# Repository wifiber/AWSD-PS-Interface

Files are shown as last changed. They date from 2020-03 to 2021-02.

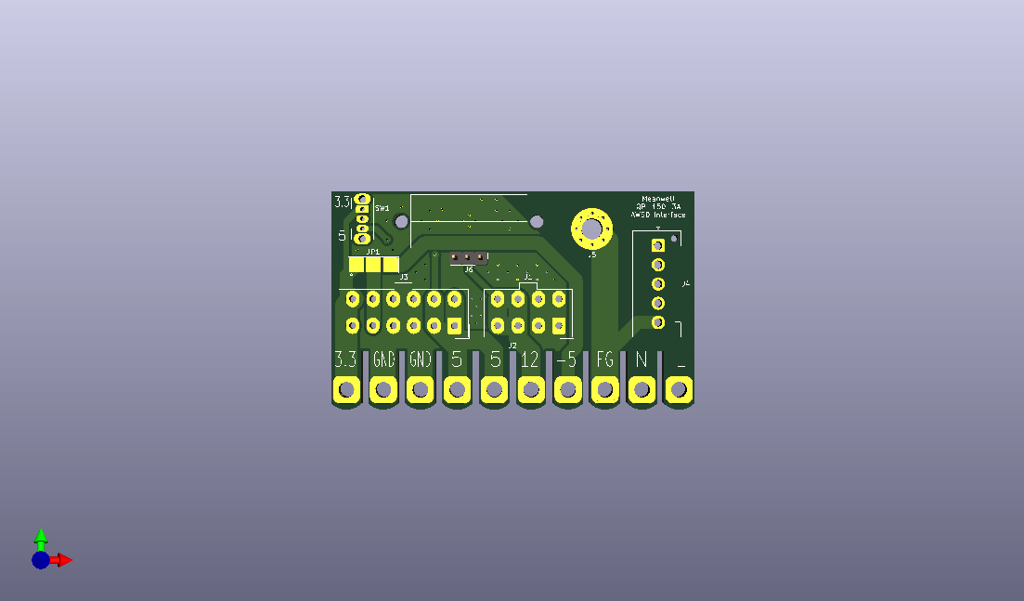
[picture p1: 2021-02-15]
psinterface-top.png

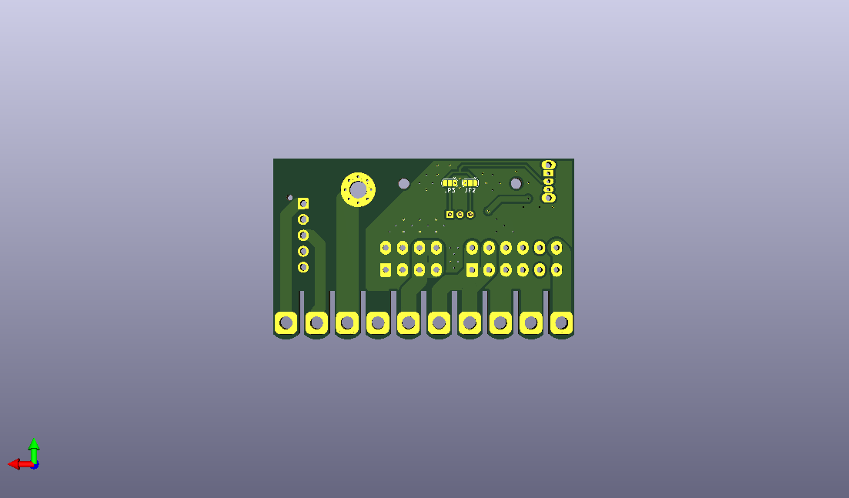
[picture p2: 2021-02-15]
psinterface-bot.png

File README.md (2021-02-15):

Atomiswave Sit Down (AWSD) arcade cabinet power supply interface board
==============

This PCB is an interface from the Meanwell QP-150-3A power supply to the stock wiring in the AWSD arcade cabinet.

The Meanwell QP-150-3A is a Quad-output PS (https://www.meanwell-web.com/en-gb/ac-dc-quad-output-enclosed-power-supply-output-qp--150--3a)
Providing 3.3V, 5V, 12V, -5V outputs

The AWSD arcade cabinet power supply is wired with a JST VH series connector for the input AC power and 2 Molex Mini-Fit JR Connectors for the output 3.3, 5, and 12 volt power.
5 conductor JST VH series (AC-N, AC-L, FG)
8 conductor Molex Mini-Fit (12V, GND)
12 conductor Molex Mini-Fit (3.3V, GND, 5V)

This interface board is designed to screw directly to the screw terminals on the Meanwell QP-150-3A. This board interfaces with the JST VH connector and the Molex Mini-Fit JR Connectors in the AWSD so no changes need to be made to the wiring harness.
There is mounting holes and solder points to add a small LCD voltage display - https://www.aliexpress.com/i/32840259666.html?spm=2114.12057483.0.0.206f62fepYHKGu
A switch can be used to switch 3.3 or 5 volts to the LCD voltage display for verification and tuning.

The AWSD arcade cabinet has 2 unused conductors in the 12-pin Molex connector. The stock AWSD power supply provides 3.3 volts on these pins that is never utilized inside the AWSD cabinet. 
I have included a 3-terminal jumper "JP1" on the interface board. It allows selection of 3.3V or -5V for these 2 pins. The rationale is that if you wanted to add the pins and wires to your AWSD arcade cabinet, you could add -5 Volt to the wiring harness and enjoy the games that require -5V.

An OSHPark Project for this board can be found here:
https://oshpark.com/shared_projects/lOjuucXz (0.5)
https://oshpark.com/shared_projects/chpeU0vp (0.4)

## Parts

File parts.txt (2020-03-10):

OSHPark Project
https://oshpark.com/shared_projects/chpeU0vp

LCD Voltage Readout
https://www.aliexpress.com/i/32840259666.html?spm=2114.12057483.0.0.206f62fepYHKGu

J1 - Molex MiniFit JR 2x4 0039290083 (gold) 0039281083 (tin)
J3 - Molex MiniFit JR 2x6 0039290123 (gold) 0039281123 (tin)
J4 - JST B5P-VH-FB-B(LF)(SN)
SW1 - C&K OS102011MA1QN1

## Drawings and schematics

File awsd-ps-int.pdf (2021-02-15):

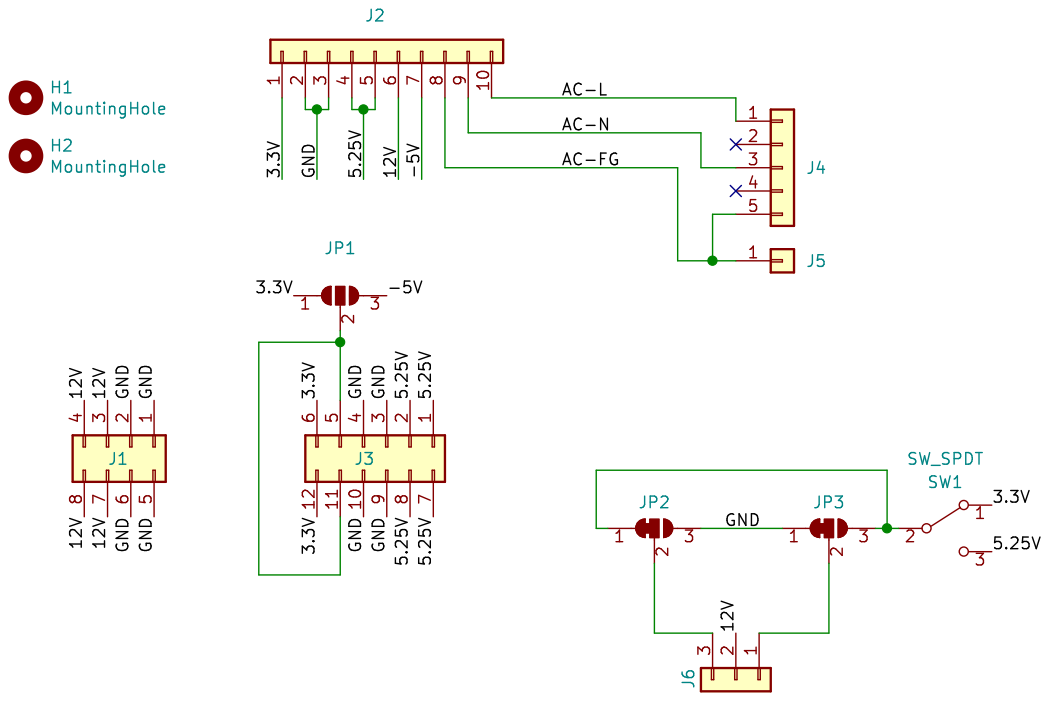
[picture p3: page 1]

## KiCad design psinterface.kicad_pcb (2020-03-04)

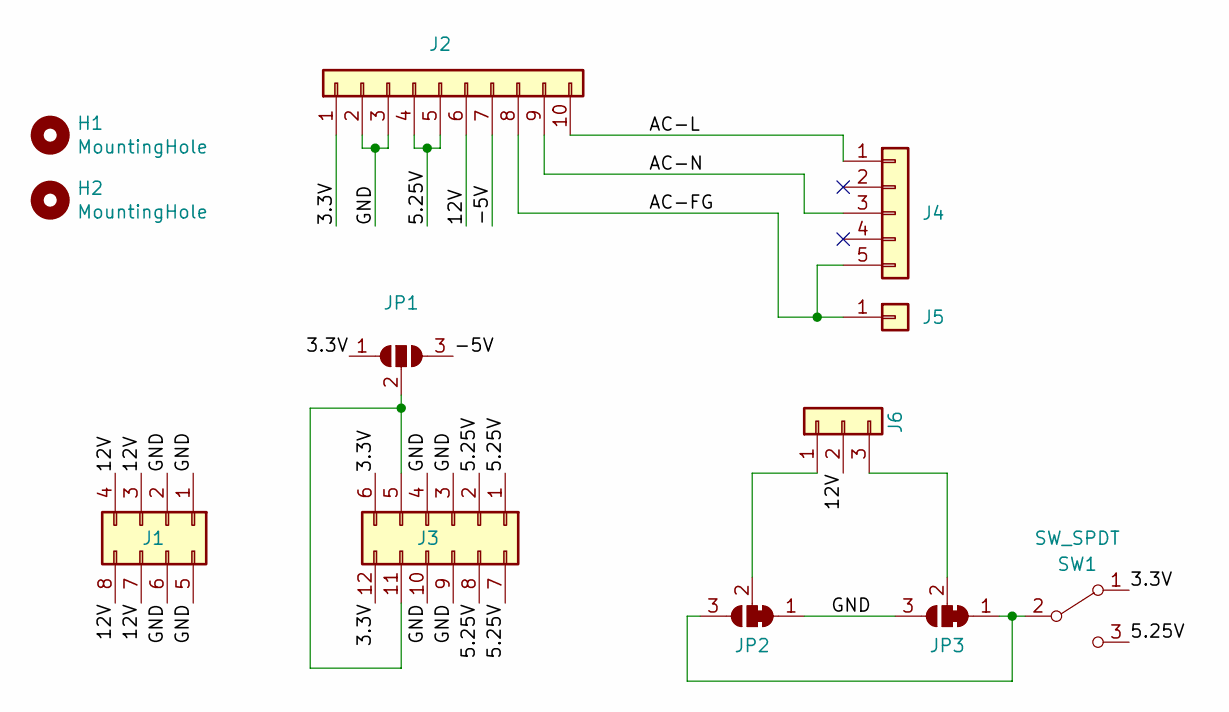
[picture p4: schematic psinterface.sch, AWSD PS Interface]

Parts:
H1, H2: MountingHole; MountingHole_2.7mm_M2.5
J1: Conn_02x04_Top_Bottom; Molex_Mini-Fit_Jr_5566-08A_2x04_P4.20mm_Vertical
J2: Conn_01x10; PSTabs_3.2mm_M3_DIN965_Pad
J3: Conn_02x06_Top_Bottom; Molex_Mini-Fit_Jr_5566-12A_2x06_P4.20mm_Vertical
J4: Conn_01x05; JST_VH_B5P-VH-FB-B_1x05_P3.96mm_Vertical
J5: Conn_01x01; MountingHole_4.3mm_M4_Pad_Via
J6: Conn_01x03; PinHeader_1x03_P2.54mm_Vertical
JP1: SolderJumper_3_Open; SolderJumper-3_P3.5mm_Open_Pad3.0x3.0mm
JP2, JP3: SolderJumper_3_Bridged12; SolderJumper-3_P1.3mm_Bridged12_RoundedPad1.0x1.5mm
SW1: SW_SPDT; SW_CuK_OS102011MA1QN1_SPDT_Angled

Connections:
/3.3V: J2.1, J3.6, J3.12, JP1.1 (A), SW1.1 (A)
/5.25V: J2.4, J2.5, J3.1, J3.2, J3.7, J3.8, SW1.3 (C)
/12V: J1.3, J1.4, J1.7, J1.8, J2.6, J6.2
/-5V: J2.7, JP1.3 (B)
/AC-FG: J2.8, J4.5, J5.1
/AC-L: J2.10, J4.1
/AC-N: J2.9, J4.3
/GND: J1.1, J1.2, J1.5, J1.6, J2.2, J2.3, J3.3, J3.4, J3.9, J3.10, JP2.1 (A), JP3.3 (B)
unnamed: J3.5, J3.11, JP1.2 (C)
unnamed: J6.1, JP2.2 (C)
unnamed: J6.3, JP3.2 (C)
unnamed: JP2.3 (B), JP3.1 (A), SW1.2 (B)

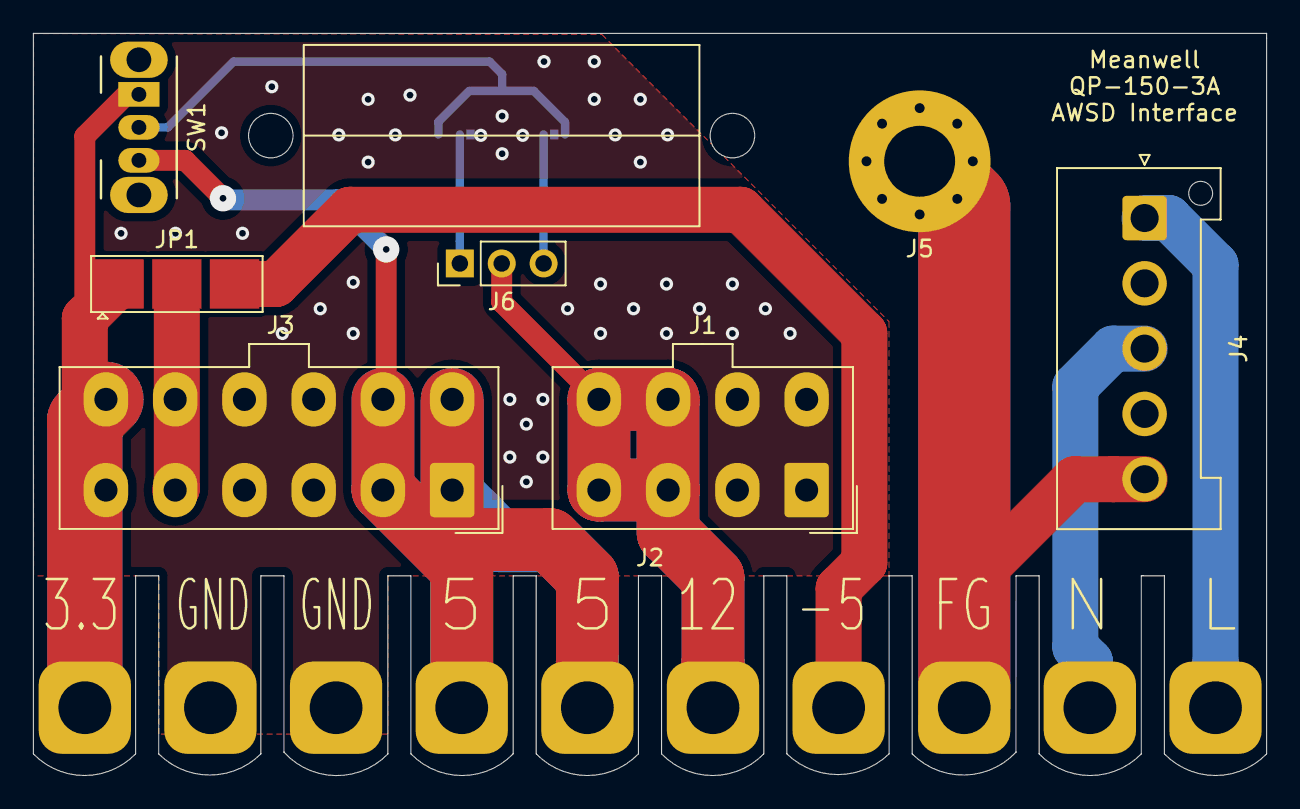
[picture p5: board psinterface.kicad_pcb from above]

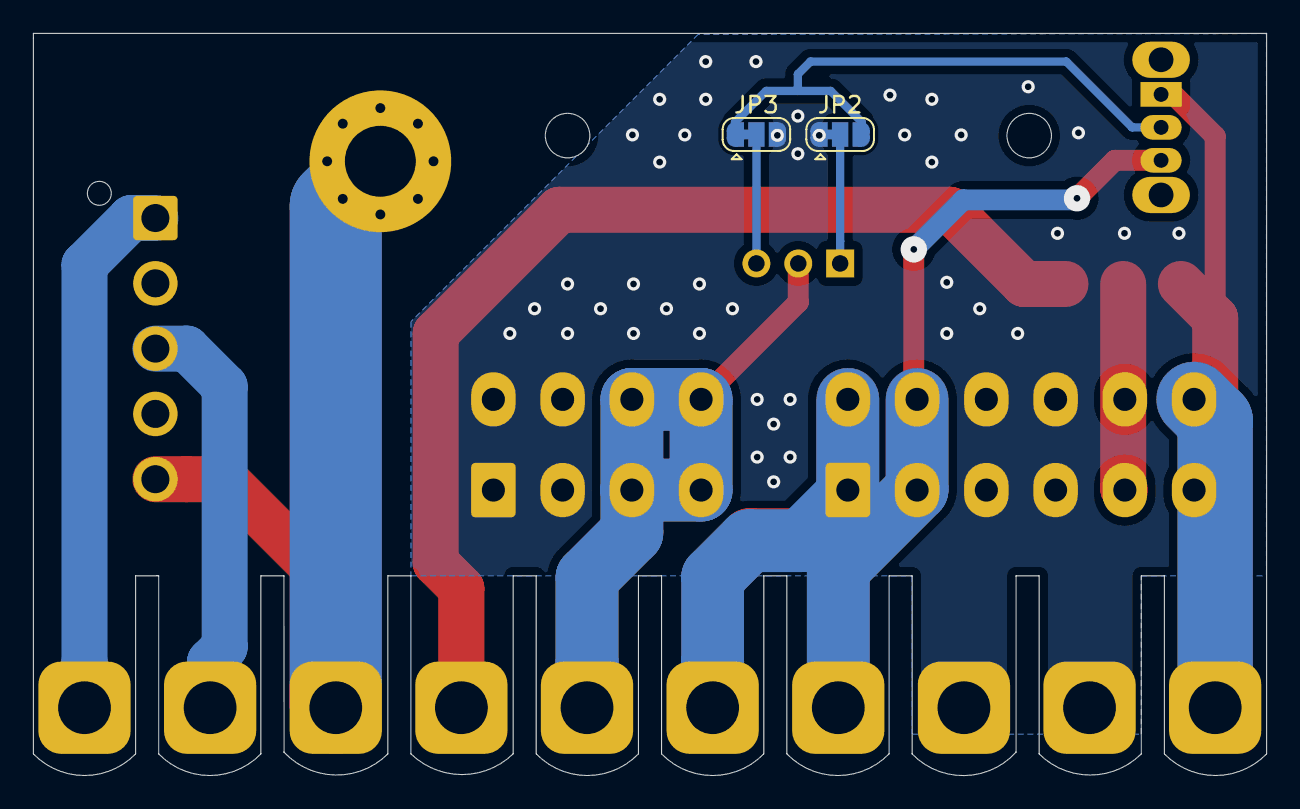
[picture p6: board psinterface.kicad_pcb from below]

Board: 2 copper layers, 74.8 x 45.0 mm, 12 parts (2 on the bottom side), 12 nets.

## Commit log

2020-02-08 Reduced sized, added text labels
    [psinterface-B_Cu.gbr, psinterface-B_Mask.gbr, psinterface-B_Paste.gbr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]
2020-02-08 Changed LCD mounting holes to 28mm
    [psinterface-B_Cu.gbr, psinterface-B_Mask.gbr, psinterface-B_Paste.gbr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]
2020-02-09 Corrected AC wiring, updated parts list
    [psinterface-B_Cu.gbr, psinterface-B_Mask.gbr, psinterface-B_Paste.gbr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]
2020-02-09 Mounting holes for LCD fixed
    [psinterface-B_Cu.gbr, psinterface-B_Mask.gbr, psinterface-B_Paste.gbr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]
2020-02-09 Rounded flanges, fixed wiring
    [psinterface-B_Cu.gbr, psinterface-B_Mask.gbr, psinterface-B_Paste.gbr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]
2020-02-25 Better use of bottom copper
    [psinterface-B_Cu.gbr, psinterface-B_Mask.gbr, psinterface-B_Paste.gbr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]
2020-03-04 J6 now 4MM, JP2/3 added to allow diff polarity LCD
    [psinterface-B_Cu.gbr, psinterface-B_Mask.gbr, psinterface-B_Paste.gbr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]
